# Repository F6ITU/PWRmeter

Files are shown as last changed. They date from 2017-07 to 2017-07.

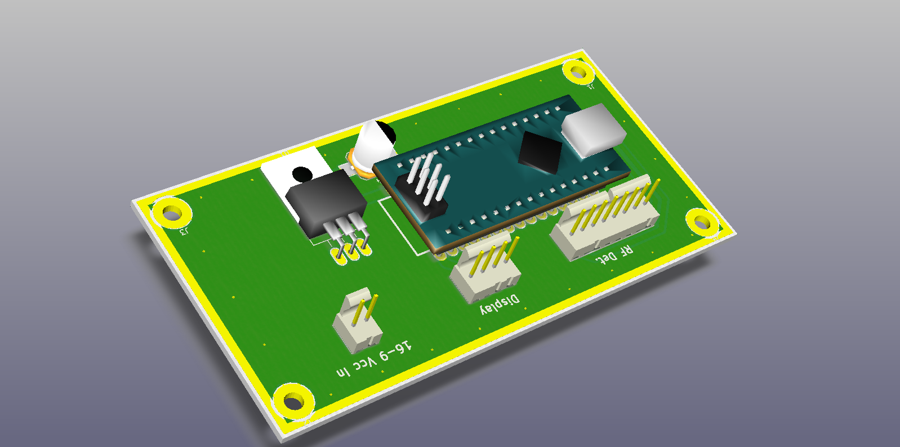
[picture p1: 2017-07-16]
PWMeter_Up.png

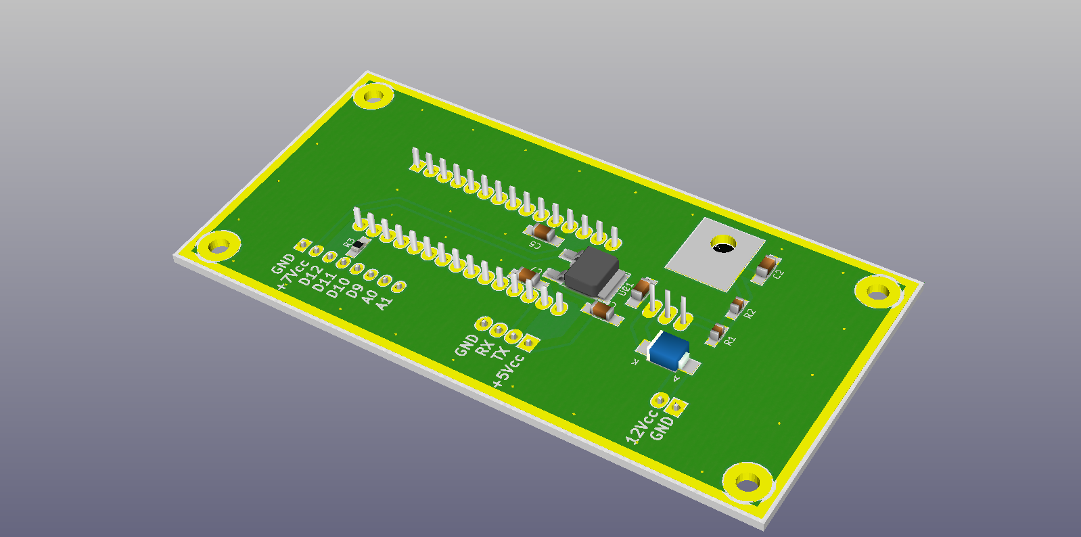
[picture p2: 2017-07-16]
PWMeter_Dwn.png

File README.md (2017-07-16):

This millwattmeter project has been driven by 

(c) Dietmar Krause, DL2SBA

License see https://creativecommons.org/licenses/by/4.0/

All software update, construction and calibration hints could be found at 

http://www.dl2sba.com/index.php/elektronik/messtechnik/rf-powermeter

This board  supports two power rails, an Arduino nano and 
3 Molex kk connectors to fit the power input, an Itead Nextion touche display, and
an "all in one" RF detector designed by SV1AFN including : 
An AD8318 det.log, a 12 bits ADC and a low noise 5V power supply. All details at 

https://www.sv1afn.com/ad8318.html

This is a one day project, even for unexperimented ham/hackers. 

Board's dimension is 5x10 cm. 
Two boards could be panelized to fit in a 10x10 standard pcb format
(Itead, Dirt Cheap pcb, Seeed Studio etc)

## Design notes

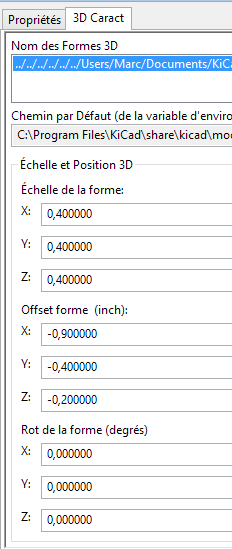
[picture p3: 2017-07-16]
arduino/nano wrl coord.png

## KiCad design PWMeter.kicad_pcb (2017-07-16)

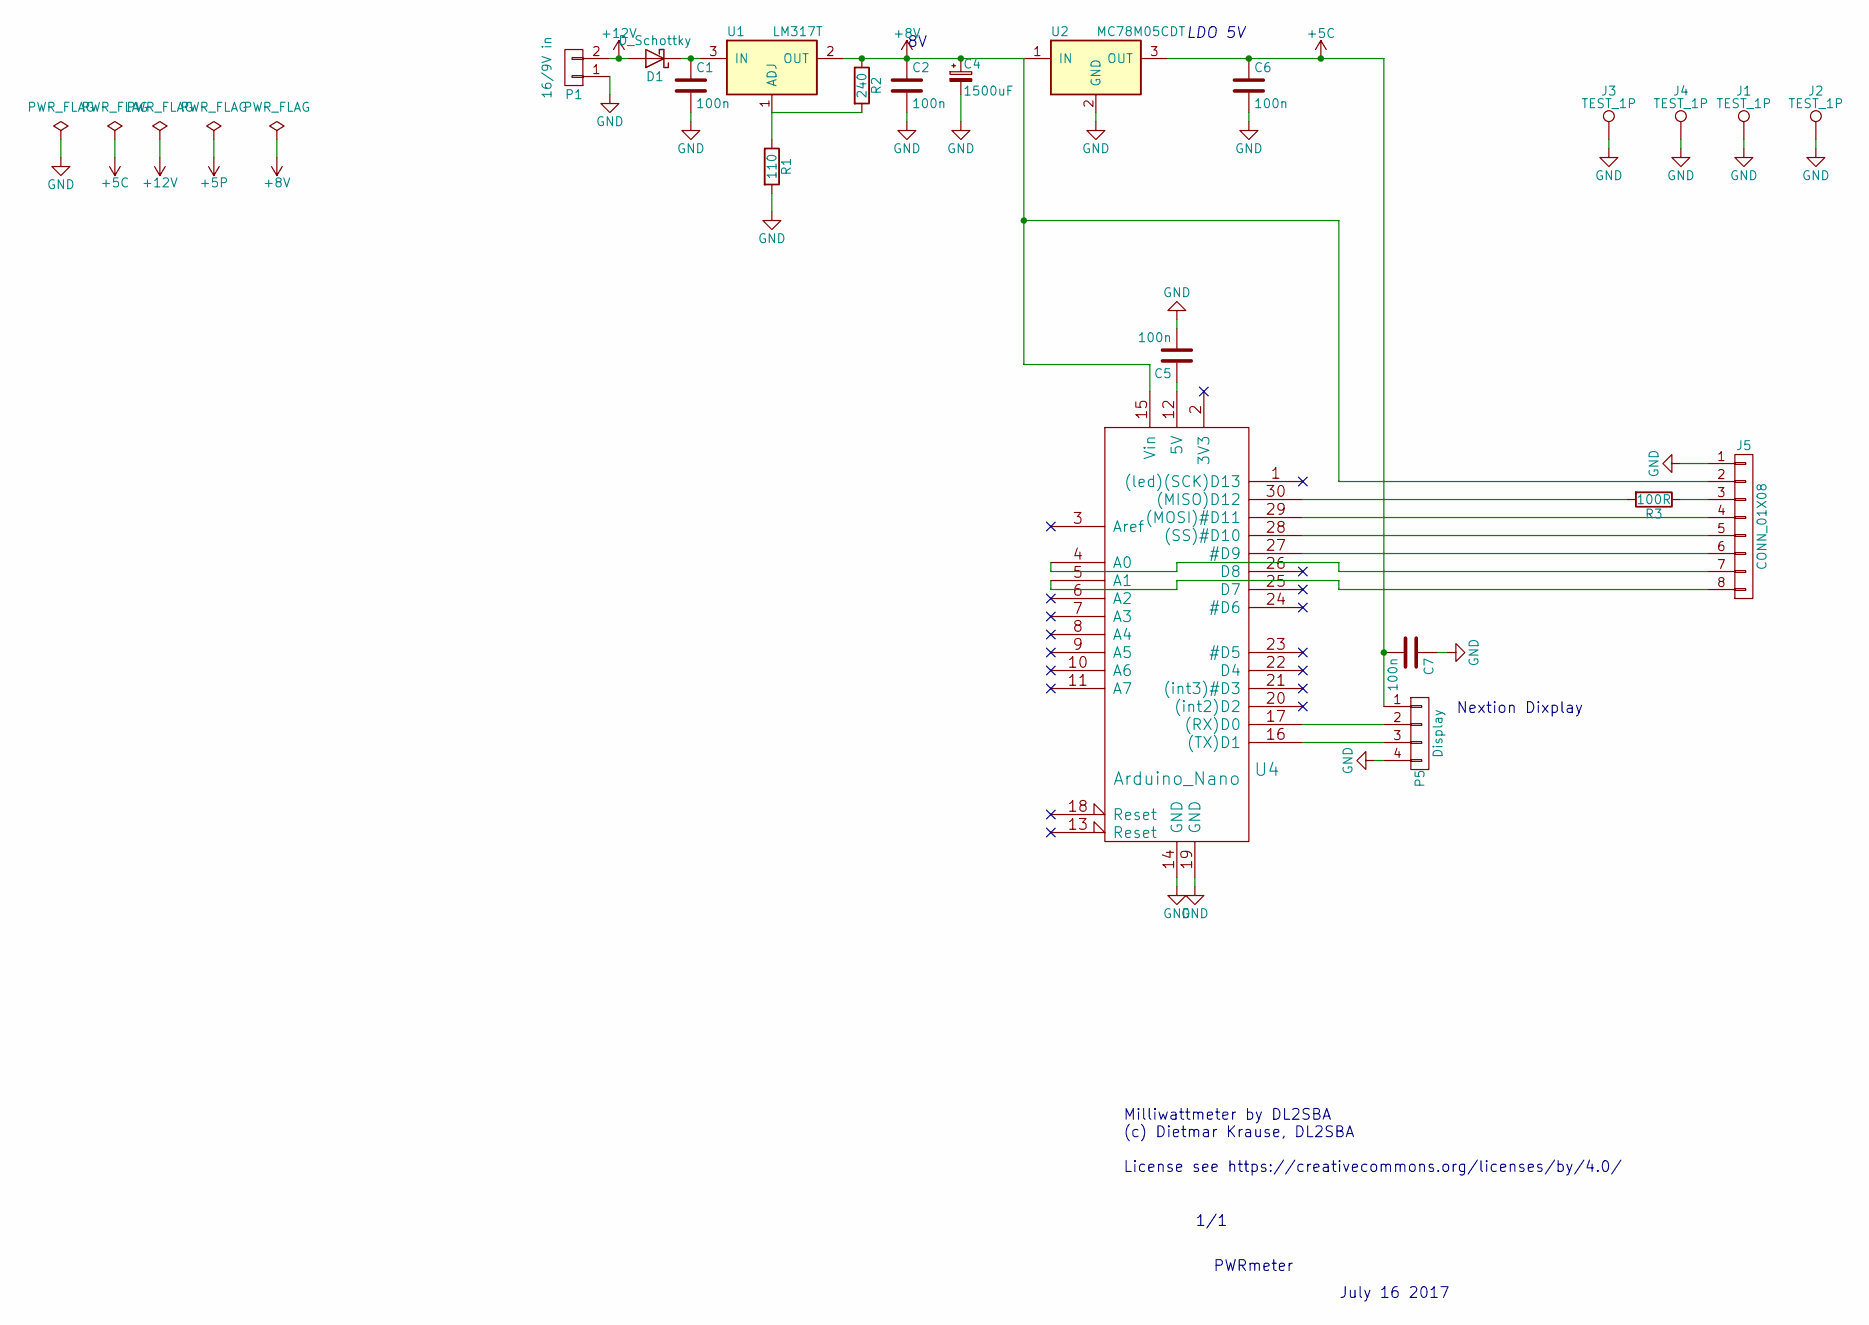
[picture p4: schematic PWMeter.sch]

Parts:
C1, C2, C5, C6, C7: 100n; C_1206_HandSoldering
C4: 1500uF; c_elec_6.3x7.7
D1: D_Schottky; SMB_Handsoldering
J1, J2, J3, J4: TEST_1P; MountingHole_3.2mm_M3_Pad
J5: CONN_01X08; kk100_22-23-2081
P1: 16/9V in; Molex_KK-6410-02_02x2.54mm_Straight
P5: Display; Molex_KK-6410-04_04x2.54mm_Straight
R1: 110; C_0805_HandSoldering
R2: 240; C_0805_HandSoldering
R3: 100R; R_0805_HandSoldering
U1: LM317T; TO-220_Neutral123_Horizontal_LargePads
U2: MC78M05CDT; TO-252-2Lead
U4: Arduino_Nano; arduino_nano

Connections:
+5C: C6.1, C7.2, P5.1, U2.3 (OUT)
+8V: C2.1, C4.1, J5.2, R2.1, U1.2 (OUT), U2.1 (IN), U4.15 (Vin)
+12V: D1.2 (A), P1.2
GND: C1.2, C2.2, C4.2, C5.2, C6.2, C7.1, J1.1, J2.1, J3.1, J4.1, J5.1, P1.1, P5.4, R1.2, U2.2 (GND), U4.14 (GND), U4.19 (GND)
unnamed: C1.1, D1.1 (K), U1.3 (IN)
unnamed: C5.1, U4.12 (5V)
unnamed: J5.3, R3.1
unnamed: J5.4, U4.29 ((MOSI)#D11)
unnamed: J5.5, U4.28 ((SS)#D10)
unnamed: J5.6, U4.27 (#D9)
unnamed: J5.7, U4.4 (A0)
unnamed: J5.8, U4.5 (A1)
unnamed: P5.2, U4.17 ((RX)D0)
unnamed: P5.3, U4.16 ((TX)D1)
unnamed: R1.1, R2.2, U1.1 (ADJ)
unnamed: R3.2, U4.30 ((MISO)D12)

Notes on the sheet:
Nextion Dixplay
LDO 5V
PWRmeter
1/1
Milliwattmeter by DL2SBA (c) Dietmar Krause, DL2SBA License see https://creativecommons.org/licenses/by/4.0/
July 16 2017

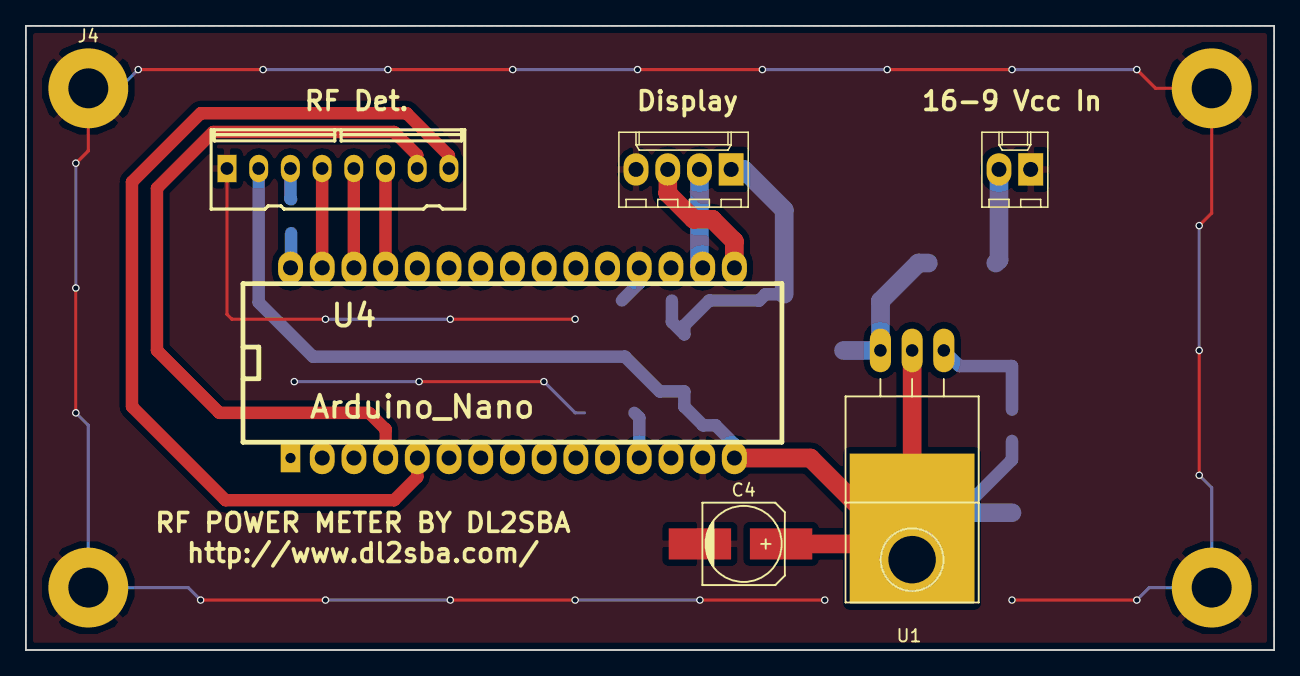
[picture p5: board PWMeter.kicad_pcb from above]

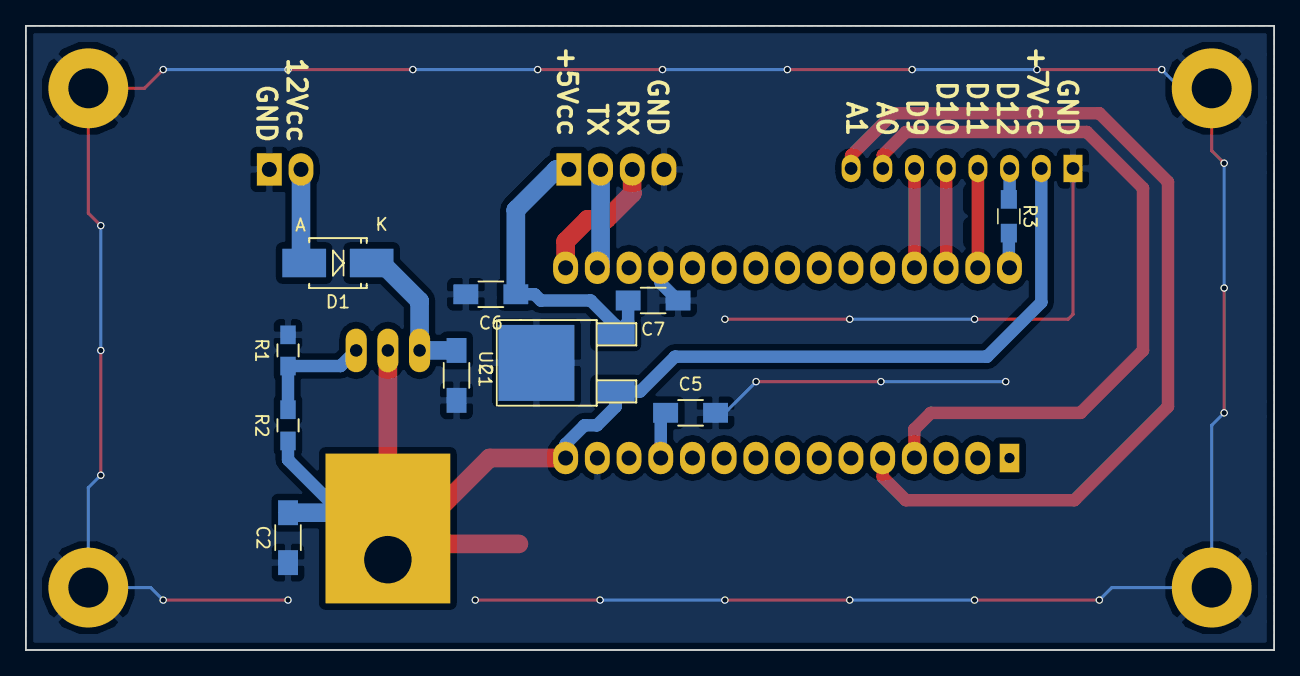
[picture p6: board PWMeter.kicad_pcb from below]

Board: 2 copper layers, 100.0 x 50.0 mm, 20 parts (10 on the bottom side), 16 nets.

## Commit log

2017-07-16 first release
    [PWMeter-B.Cu.gbl, PWMeter-B.Mask.gbs, PWMeter-B.Paste.gbp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]
2017-07-16 minor changes on sylkmask
    [PWMeter-B.Cu.gbl, PWMeter-B.Mask.gbs, PWMeter-B.Paste.gbp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]
2017-07-16 resistor added on MISO trace
    [PWMeter.sch]
